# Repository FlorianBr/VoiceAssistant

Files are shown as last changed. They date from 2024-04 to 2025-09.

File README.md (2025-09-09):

# Voice Assistant for HA

After playing around with different hardwares and the settings (see [here](https://github.com/FlorianBr/ESPHome.Assist)) I started to create a (more or less) final voice assistant including case and so on

TODO:

- [x] First tests with the ReSpeaker Lite
- [ ] 3D parts for mounting the ReSpeaker into the Cube
- [ ] 3D parts for the speaker
- [ ] Maybe: 3D parts for the LEDs
- [ ] Hardware: Wiring of ReSpeaker, Speaker, LEDs, Power Supply...
- [ ] Software: Basic Voice Assistant
- [ ] Software: Media Player
- [ ] Software: LED-Effects
- [ ] Software: Confirmation MP3 in the ESPs flash
- [ ] Software: Custom wake-word
- [ ] Software: Better state changes and documentation of states

## Version 1: ESP32S3 with I2S Mic and Audio Amplifier (deprecated!)

> [!WARNING]
> Due to a bug in ESPHome the Voice Assistant won't work in combination with local wake word detection. The mic gain is broken for the VA, so it will listen to the wake word but the audio stream is not loud enough. Therefore I moved on to Version 2 with a ReSpeaker Lite.

### The Case

The case is based on a 3D printed Companion Cube made by woodyhead101 available on [thingiverse](https://www.thingiverse.com/thing:6468441)

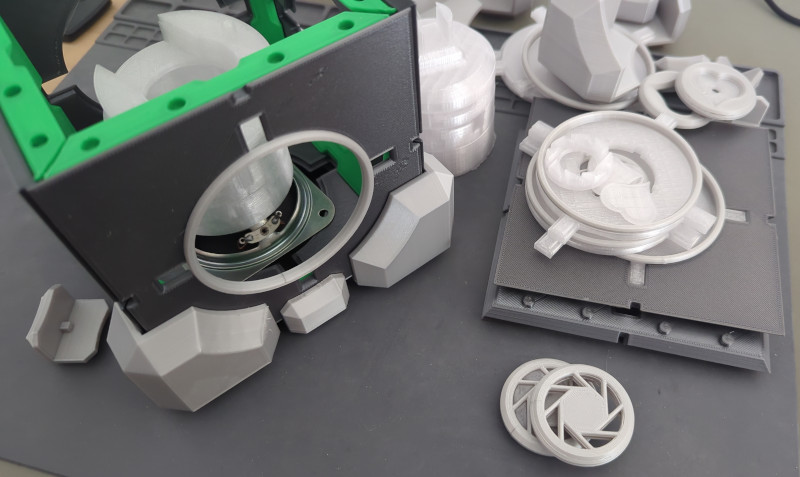
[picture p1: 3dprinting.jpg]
3D Parts


Most of the outer parts are not modified, there is only one exception: For the microphone I modified one of the Aperture-Inlays. I did that in the slicer it self with boolean operations so there is no 3D File for that.

Besides that I added holders for the ESP32, LED strip and the amplifiers. The speaker is screwed to the backwards facing plate and the other components hold by 3D printed parts stacked onto the speaker. The parts are far from perfect, but it works. But next time I would design it differently...

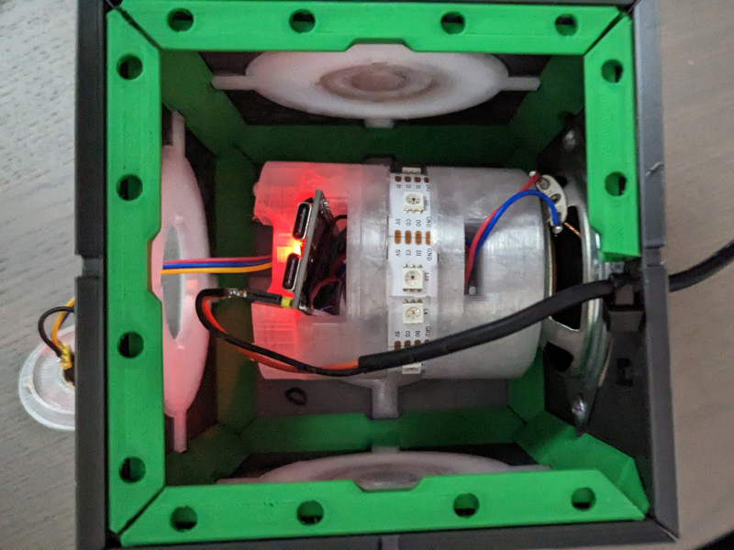
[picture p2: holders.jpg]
Electronic holders

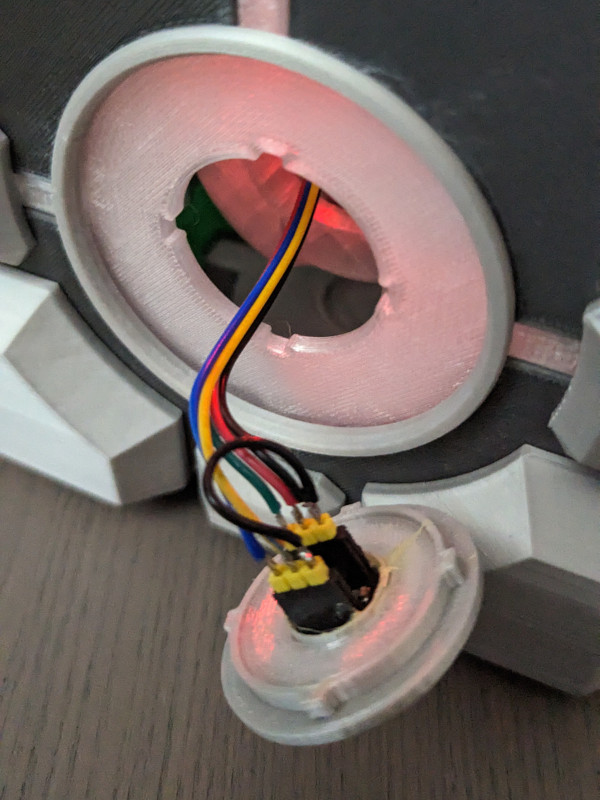
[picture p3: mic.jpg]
Microphone

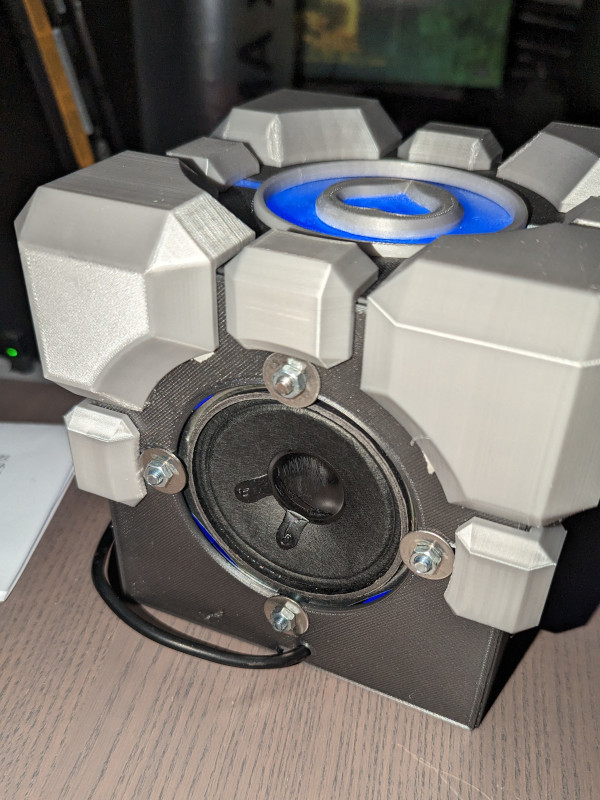
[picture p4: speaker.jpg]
Speaker


### The Hardware

The ESP32 is a chinese clone of Espressifs ESP32-S3-DevKitC with slightly different pinning. The on-board RGB-LED is at IO48 instead of IO38 for example.

On the breadboard I still have an additional LED and a button, both removed in the final design. Also the led strip is longer.

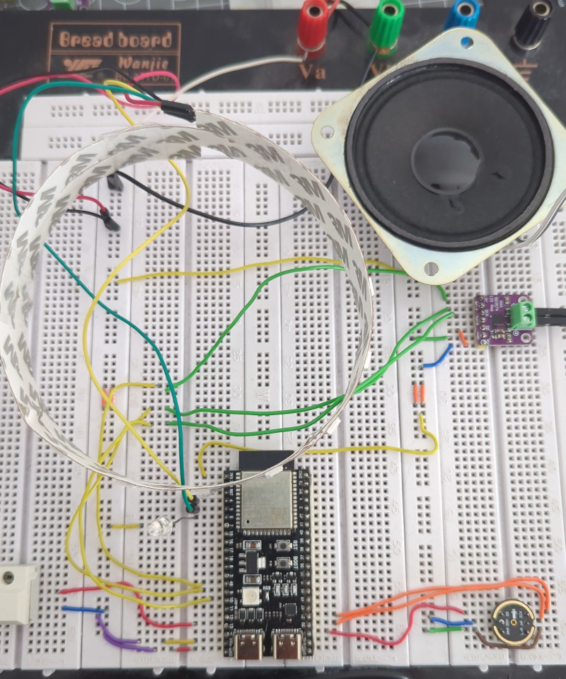
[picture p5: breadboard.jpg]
Breadboard


#### Pinnings

##### MAX98357

- LRC  - ESP32 GPIO46
- BCK  - ESP32 GPIO9
- DIN  - ESP32 GPIO10
- GAIN - not connected
- SD   - VDD (Channel left selected)
- GND  - GND
- VDD  - ESP32 3v3

##### INMP441

- SCK - ESP32 GPIO21
- WS  - ESP32 GPIO20
- L/R - GND
- SO  - ESP32 GPIO19
- VDD - ESP32 3v3
- GND - GND

##### LED Strip

- 5V  - 5V
- CI  - ESP32 GPIO5
- DI  - ESP32 GPIO4
- GND - GND

##### ESP32

- GPIO4  - LED Strip DI
- GPIO5  - LED Strip CI
- GPIO9  - MAX98357 BCK
- GPIO10 - MAX98357 DIN
- GPIO19 - INMP441 SO
- GPIO20 - INMP441 WS
- GPIO21 - INMP441 SCK
- GPIO46 - MAX98357 LRC
- GPIO48 - On-Board RGB-LED

### The software

#### Local Wake word

The ESP is powerful enough for micro_wake_word, meaning: The detection of the wake word runs directly on the ESP32. Instead of the official models I use a model found in [Florian Wartner Collection](https://github.com/fwartner/home-assistant-wakewords-collection), and added the necessary JSON to use it.

For your own training have a look at the Docs [here](https://github.com/kahrendt/microWakeWord) and [here](https://github.com/dscripka/openWakeWord)

## Version 2: ReSpeaker Lite

Currently a work in progress, using a [ReSpeaker Lite](https://github.com/respeaker/ReSpeaker_Lite/tree/master).
A first test with a stripped down config from the [Koala Satellite](https://github.com/formatBCE/Koala-Satellite/tree/main) was promissing.
I am still planning to build it into the companion cube, but need to design a few new parts for mounting the PCB and LEDs.

## States, Conditions and Light

States:

| Name | Condition | LED-Ring |
|---|---|---|
| starting  | Power-On | Red, rotating |
| idle | VA is ready, waiting for WW | Off |
| wakeword  | WW detected | Green |
| VA start  | VA is starting | Orange |
| listening | VA is listening | Green, fast pulse  |
| thinking  | Parsing audio data | Orange, fast pulse |
| replying  | VA is answering | Blue |
| error | Generic/unknown error | Red, Fast Pulse |
| muted | WakeWord detection OFF | Red, Slow Pulse |

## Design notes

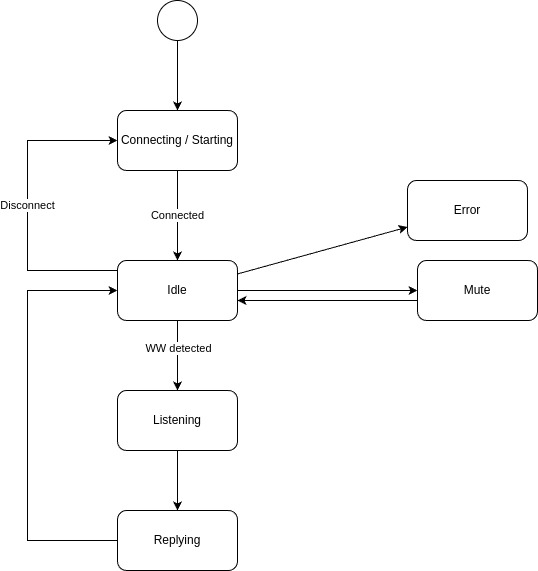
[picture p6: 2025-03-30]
Software/states.jpg

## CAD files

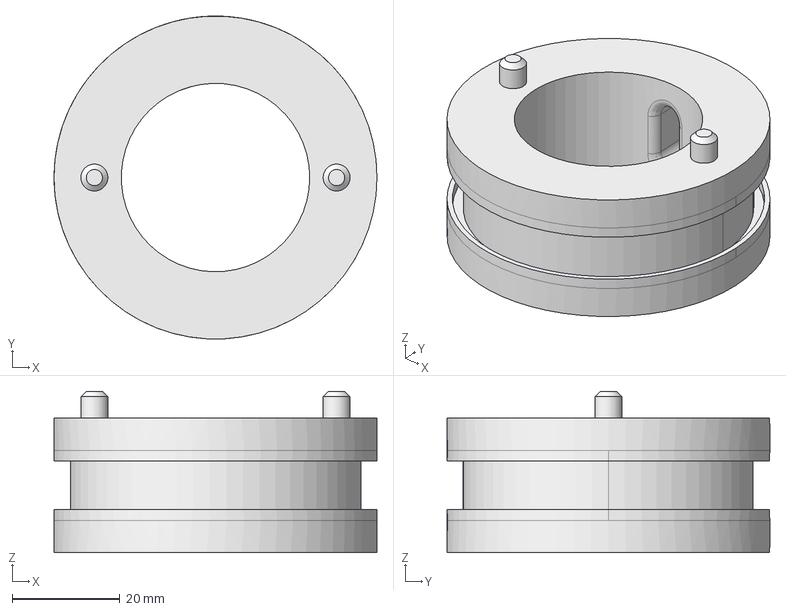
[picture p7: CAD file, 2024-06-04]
3D-Parts/HAAssist_LED_v2.FCStd
60.0 x 60.0 x 30.0 mm

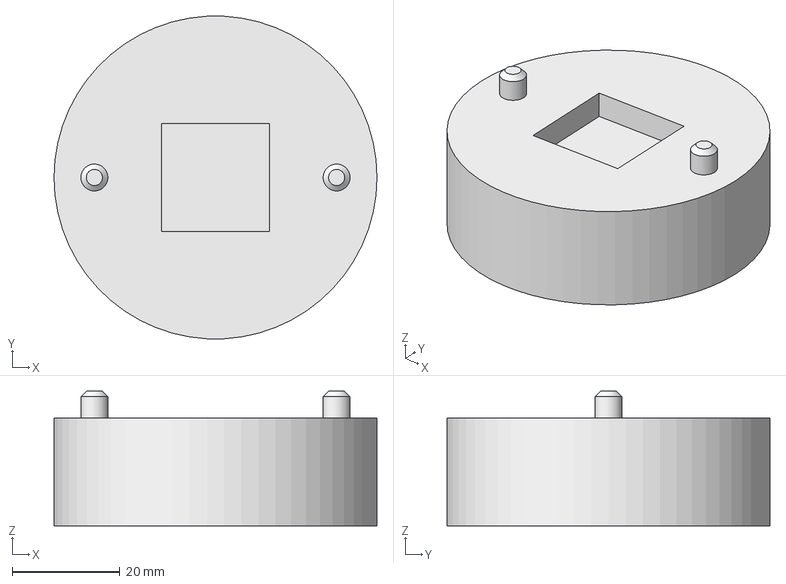
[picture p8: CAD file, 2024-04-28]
3D-Parts/HAAssist_1.FCStd
60.0 x 59.9 x 25.0 mm

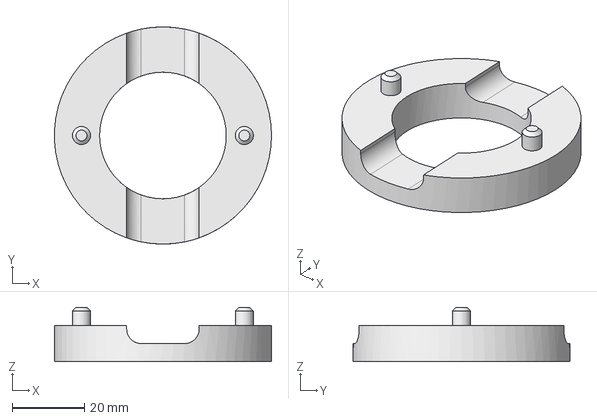
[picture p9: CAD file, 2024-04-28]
3D-Parts/HAAssist_3.FCStd
60.0 x 60.0 x 15.0 mm

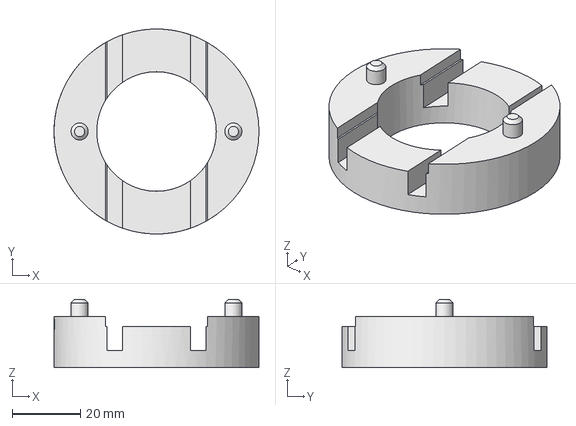
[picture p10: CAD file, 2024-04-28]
3D-Parts/HAAssist_2.FCStd
60.0 x 60.0 x 20.0 mm

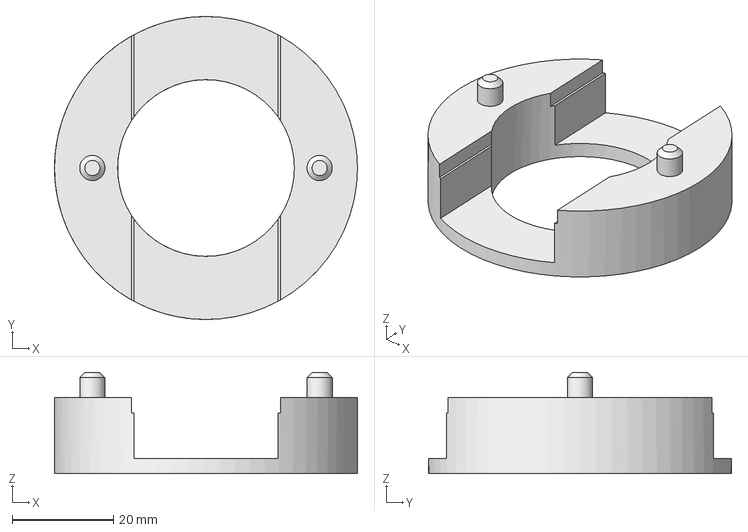
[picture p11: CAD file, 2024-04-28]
3D-Parts/HAAssist_ESP32.FCStd
60.0 x 60.0 x 20.0 mm

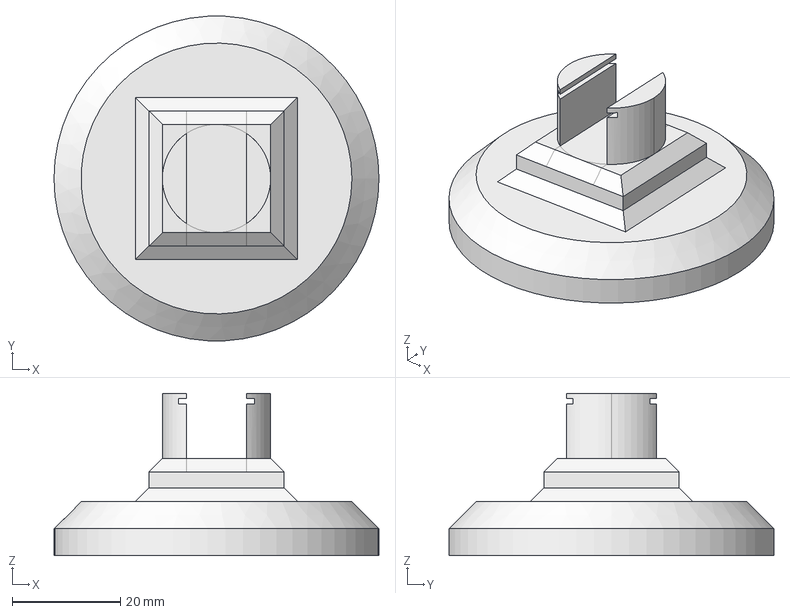
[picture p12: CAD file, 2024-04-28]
3D-Parts/HAAssist_4.FCStd
60.0 x 59.9 x 30.0 mm

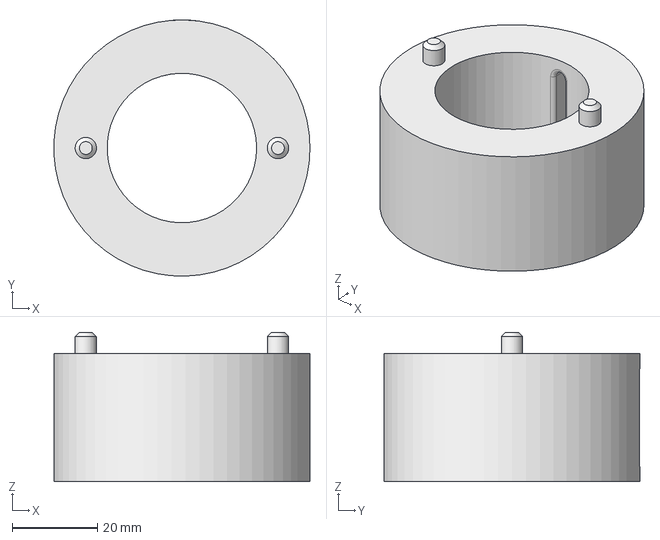
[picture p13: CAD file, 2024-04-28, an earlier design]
3D-Parts/HAAssist_LED.FCStd
60.0 x 60.0 x 35.0 mm

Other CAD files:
3D-Parts/HAAssist_Amp_v2.FCStd
3D-Parts/HAAssist_1.stl
3D-Parts/HAAssist_2.stl
3D-Parts/HAAssist_3.stl
3D-Parts/HAAssist_4.stl
3D-Parts/HAAssist_Amp_v2.stl
3D-Parts/HAAssist_ESP32.stl
3D-Parts/HAAssist_LED.stl
3D-Parts/HAAssist_LED_v2.stl

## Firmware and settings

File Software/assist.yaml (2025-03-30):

# Assist for Home Assistant
# Board: ESP32-S3 DevKit
# Microphone: INMP441
# Speaker: MAX98357
# Outputs: LED Strip
# Portal WAVs: https://theportalwiki.com/wiki/Turret_voice_lines

esphome:
  name: assistcube
  comment: Voice Assist Cube on ESP32-S3
  friendly_name: VA Cube
  name_add_mac_suffix: false
  min_version: 2025.2.0
  on_boot:
    priority: -100
    then:
      - lambda: id(sys_phase) = ${state_starting};
      - script.execute: control_ui
      - media_player.volume_set: 60%

esp32:
  board: esp32-s3-devkitc-1
  variant: ESP32S3
  flash_size: 16MB
  framework:
    type: esp-idf
    version: latest
    sdkconfig_options:
      CONFIG_ESP32_S3_BOX_BOARD: "y"
      CONFIG_ESP32S3_DEFAULT_CPU_FREQ_240: "y"
      CONFIG_ESP32S3_DATA_CACHE_64KB:      "y"
      CONFIG_ESP32S3_DATA_CACHE_LINE_64B:  "y"
      CONFIG_ESP32_WIFI_STATIC_RX_BUFFER_NUM: "16"
      CONFIG_ESP32_WIFI_DYNAMIC_RX_BUFFER_NUM: "512"
      CONFIG_TCPIP_RECVMBOX_SIZE: "512"
      CONFIG_TCP_SND_BUF_DEFAULT: "65535"
      CONFIG_TCP_WND_DEFAULT: "512000"
      CONFIG_TCP_RECVMBOX_SIZE: "512"

psram:
  mode: octal
  speed: 80MHz

api:
  services:
    - service: start_va
      then:
        - voice_assistant.start
    - service: stop_va
      then:
        - voice_assistant.stop

ota:
  - platform: esphome

wifi:
  ssid: !secret wifi_ssid
  password: !secret wifi_pass
  # power_save_mode: none
  enable_on_boot: True
  fast_connect: True
  output_power: 8.5

web_server:
  port: 80
  include_internal: true

logger:
  hardware_uart: USB_SERIAL_JTAG

substitutions:
  state_starting: '0'
  state_idle: '1'
  state_wakeword: '2'
  state_vastart: '3'
  state_listening: '4'
  state_thinking: '5'
  state_replying: '6'
  state_error: '11'
  state_muted: '12'

globals:
  - id: sys_phase
    type: int
    restore_value: no
    initial_value: ${state_starting}

text_sensor:
  - platform: template
    name: "Current state"
    update_interval: 500ms
    lambda: !lambda |-
        switch(id(sys_phase)) {
          default:
            return {"Unknown"};
            break;
          case ${state_starting}:
            return {"Starting"};
            break;
          case ${state_idle}:
            return {"Idle"};
            break;
          case ${state_wakeword}:
            return {"WakeWord"};
            break;
          case ${state_vastart}:
            return {"VA Start"};
            break;
          case ${state_listening}:
            return {"Listening"};
            break;
          case ${state_thinking}:
            return {"Thinking"};
            break;
          case ${state_replying}:
            return {"Replying"};
            break;
          case ${state_error}:
            return {"Error"};
            break;
          case ${state_muted}:
            return {"Muted"};
            break;
        }

############################ Buttons / Switches

switch:
  - platform: template
    name: Mute
    id: enable_mute
    optimistic: true
    restore_mode: RESTORE_DEFAULT_OFF
    on_turn_on:
      - script.execute: turn_off_wake_word
    on_turn_off:
      - script.execute: turn_on_wake_word
  - platform: restart
    id: trigger_restart
    name: "Restart"

############################ Lights

spi:
  mosi_pin: 4
  clk_pin: 5

light:
  - platform: esp32_rmt_led_strip
    rgb_order: GRB
    pin: GPIO48
    num_leds: 1
    chipset: SK6812
    name: "On Board LED"
    effects:
      - pulse:
          name: "Fast Pulse"
          transition_length: 250ms
          update_interval: 250ms
          min_brightness: 0%
          max_brightness: 50%
      - pulse:
          name: "Slow Pulse"
          transition_length: 500ms
          update_interval: 500ms
          min_brightness: 0%
          max_brightness: 50%
  - platform: spi_led_strip
    num_leds: 9
    id: led_strip
    name: "RGB LED Strip"
    data_rate: 200kHz
    effects:
      - addressable_color_wipe:
          name: "Rotating Red"
          colors:
            - red: 100%
              green: 0%
              blue: 0%
              num_leds: 1
            - red: 0%
              green: 0%
              blue: 0%
              num_leds: 7
          add_led_interval: 75ms
          reverse: false
      - pulse:
          name: "Fast Pulse"
          transition_length: 250ms
          update_interval: 250ms
          min_brightness: 0%
          max_brightness: 50%
      - pulse:
          name: "Slow Pulse"
          transition_length: 500ms
          update_interval: 500ms
          min_brightness: 0%
          max_brightness: 50%
      - pulse:
          name: "Super Slow Pulse"
          transition_length: 2s
          update_interval: 2s
          min_brightness: 0%
          max_brightness: 50%

############################ Audio

i2s_audio:
  - id: i2s_in
    i2s_lrclk_pin: GPIO20   # INMP441 WS
    i2s_bclk_pin: GPIO21    # INMP441 SCK
  - id: i2s_out
    i2s_lrclk_pin: GPIO46   # MAX98357 LRC
    i2s_bclk_pin: GPIO9     # MAX98357 BCK
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

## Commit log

2024-04-28 Added 3D Parts (work in progress!)
    [HAAssist_1.FCStd, HAAssist_1.stl, HAAssist_2.FCStd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]
2024-06-04 Update after building the case
    [HAAssist_LED_v2.FCStd, HAAssist_LED_v2.stl]
